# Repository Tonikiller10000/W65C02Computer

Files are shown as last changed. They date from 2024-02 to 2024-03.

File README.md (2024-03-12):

# W65C02Computer

### Description:
This is an 8 bit computer made with the W65C02 processor inspired by Ben Eater.
After board arrival, I will test the clk maximum speed (20MHz), some methods to write into ROM (take\`s too much time to write to it) and some other experiments with this design, beeing made mostly after the Ben Eater\`s original design.

### Features:
 - 8 bit processor
 - 1-10MHz CLK
 - 16K RAM
 - 32K ROM
 - USB C Powered
 - Serial interface
 - Multiple GPIO

<table>
  <tr>
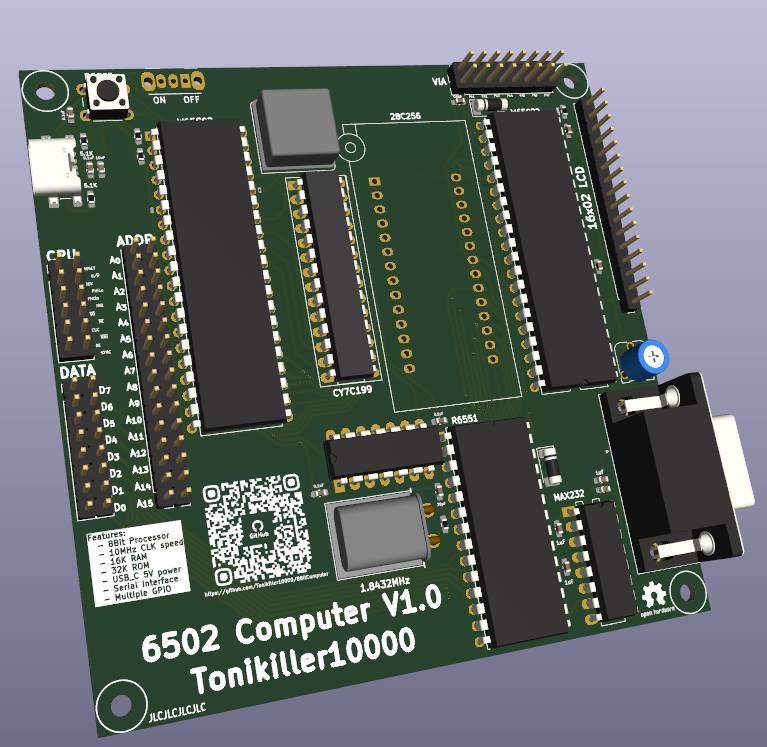
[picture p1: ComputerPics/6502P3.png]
    <td></td>
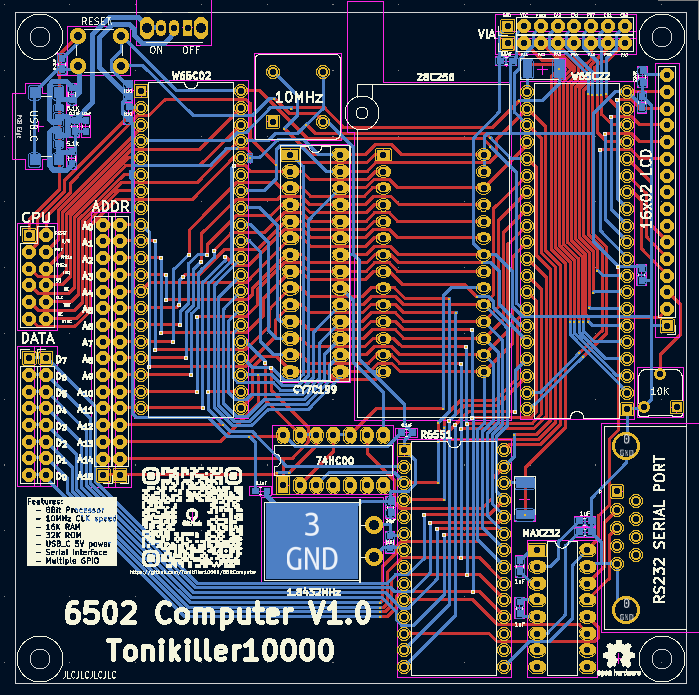
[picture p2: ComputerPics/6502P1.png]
    <td></td>
  </tr>
 </table>

Schematic:  
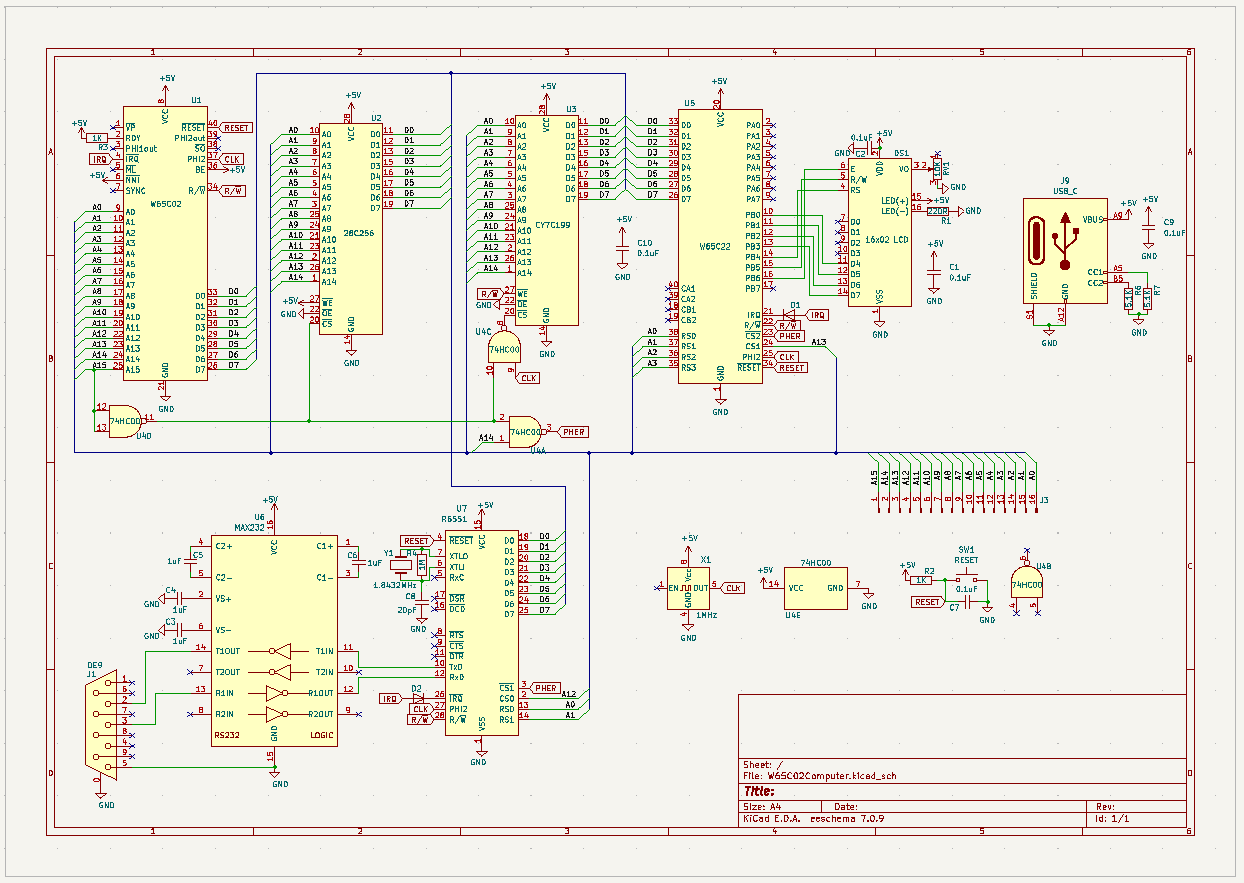
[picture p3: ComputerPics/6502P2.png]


Datasheets:
- W65C02 (Processor): https://eater.net/datasheets/w65c02s.pdf
- W65C22 (VIA): https://eater.net/datasheets/w65c22.pdf
- AT28C256 (32K x 8 EERPOM): https://ww1.microchip.com/downloads/en/DeviceDoc/doc0006.pdf
- CY7c199  (32K x 8  RAM): https://media.digikey.com/pdf/Data%20Sheets/Cypress%20PDFs/CY7C199.pdf
- R6551 (ACIA): https://pdf.datasheetcatalog.com/datasheets/2300/501026_DS.pdf
- MAX232 (Serial Port Driver): https://www.ti.com/lit/ds/symlink/max232.pdf
- MAX232 (Second datasheet): https://pdf1.alldatasheet.com/datasheet-pdf/view/73113/MAXIM/MAX232EPE.html
- 74HC00 (NAND Gate): https://www.diodes.com/assets/Datasheets/74HC00.pdf

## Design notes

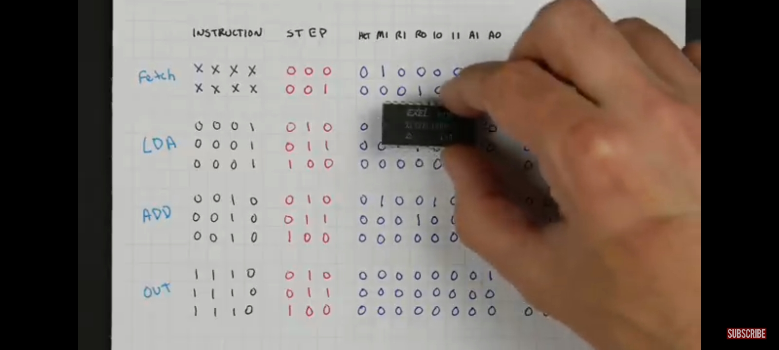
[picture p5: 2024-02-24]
ComputerPics/Screenshot_20221124-123017_YouTube.jpg

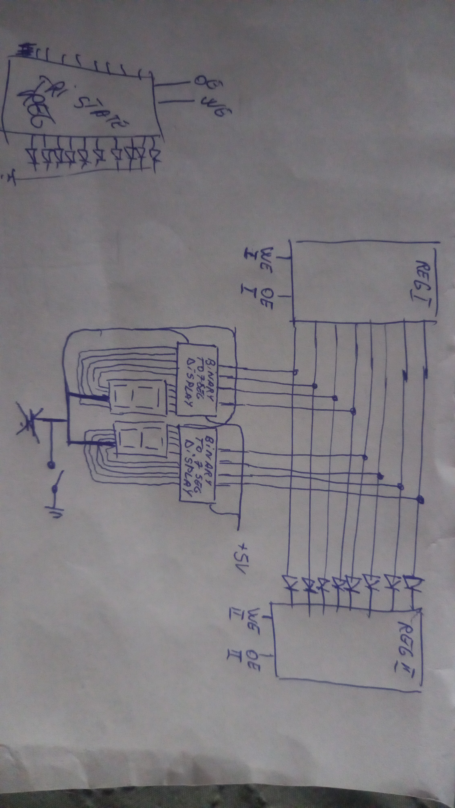
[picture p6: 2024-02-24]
ComputerPics/IMG-20220810-WA0000.jpeg

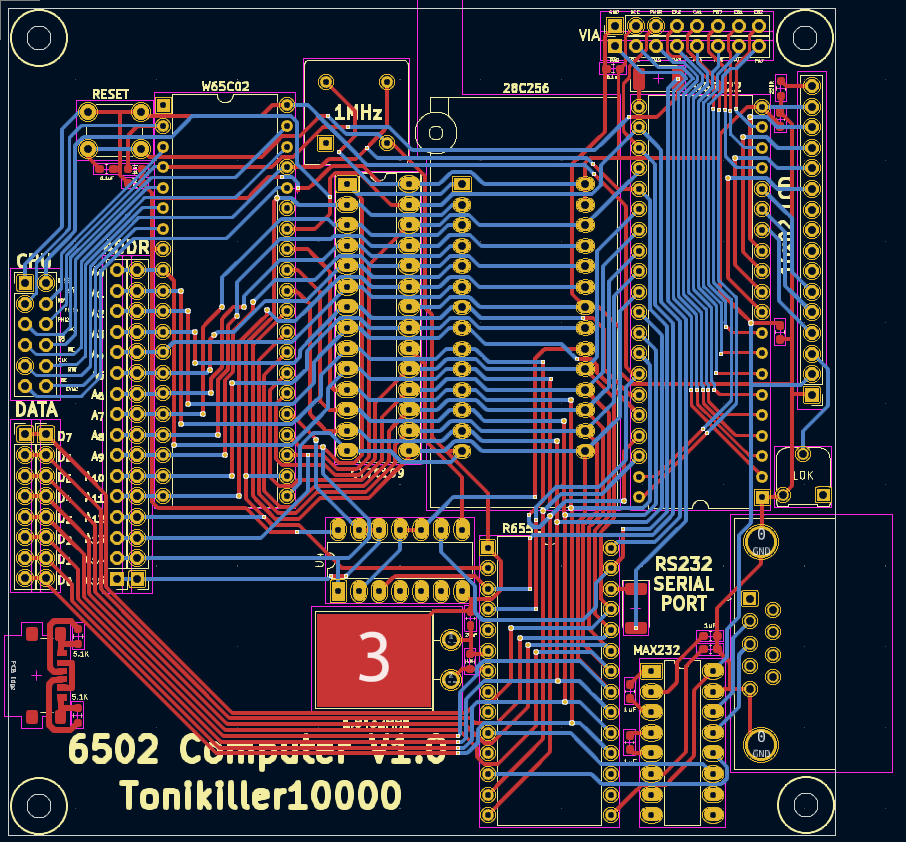
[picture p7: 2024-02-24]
ComputerPics/Screenshot 2024-01-11 041759.png

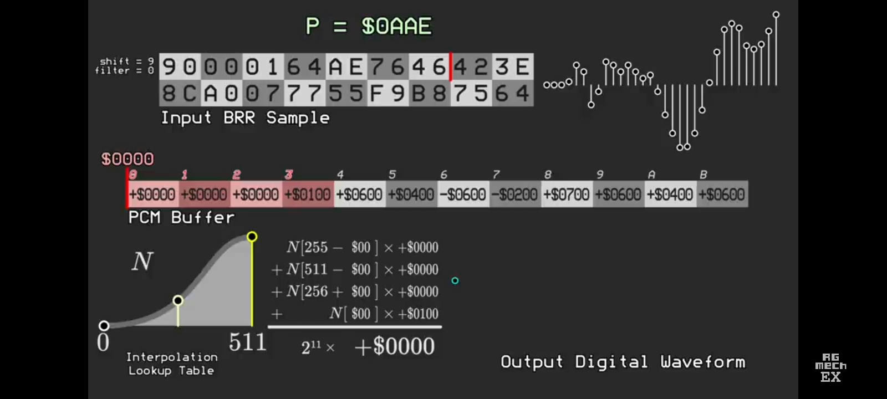
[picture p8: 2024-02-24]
ComputerPics/Screenshot_20220821-015402_YouTube.jpg

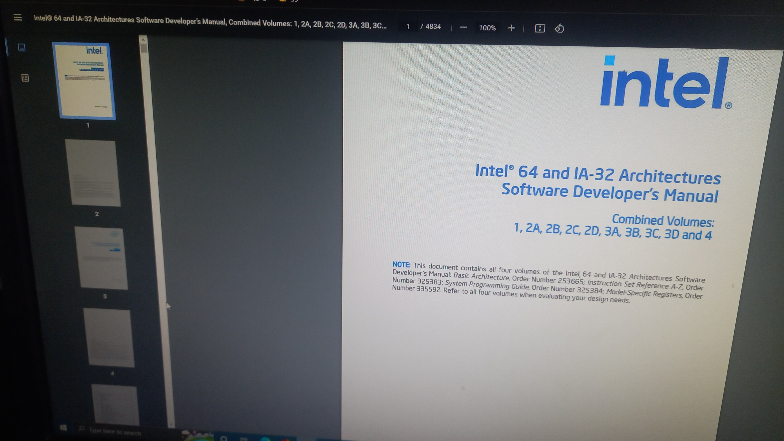
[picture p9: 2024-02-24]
ComputerPics/IMG-20220813-WA0000.jpeg

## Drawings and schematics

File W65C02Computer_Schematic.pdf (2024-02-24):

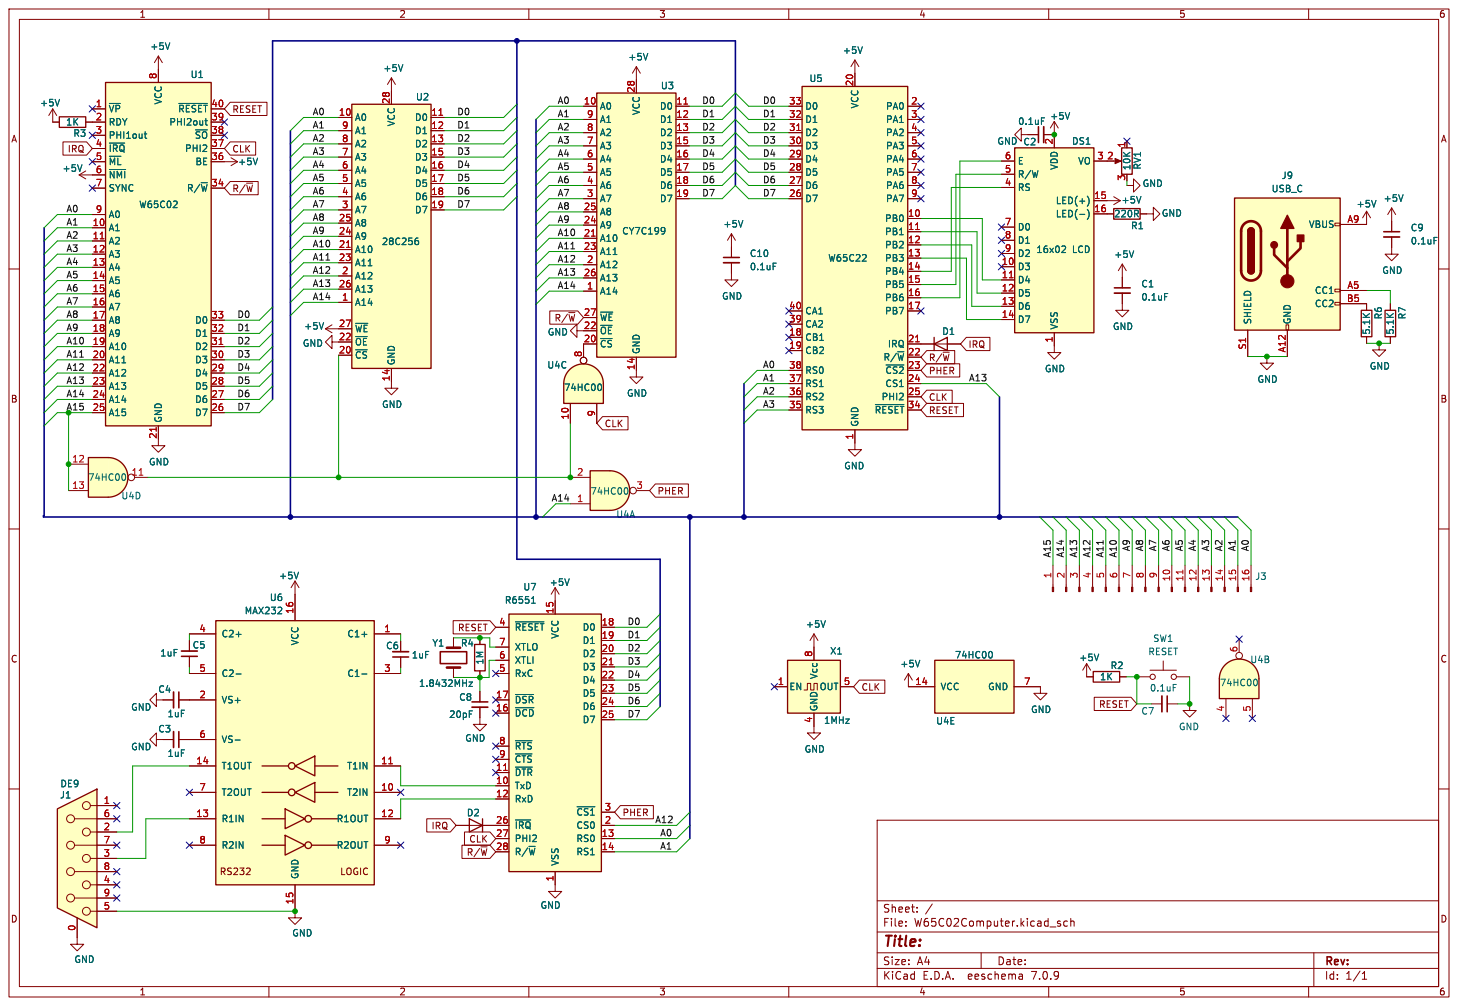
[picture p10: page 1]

1 TxD 10 ~{DTR} 11 RxD 12 RS0 13 RS1 14 VCC 15

4 OUT 5 Vcc 8 GND GND

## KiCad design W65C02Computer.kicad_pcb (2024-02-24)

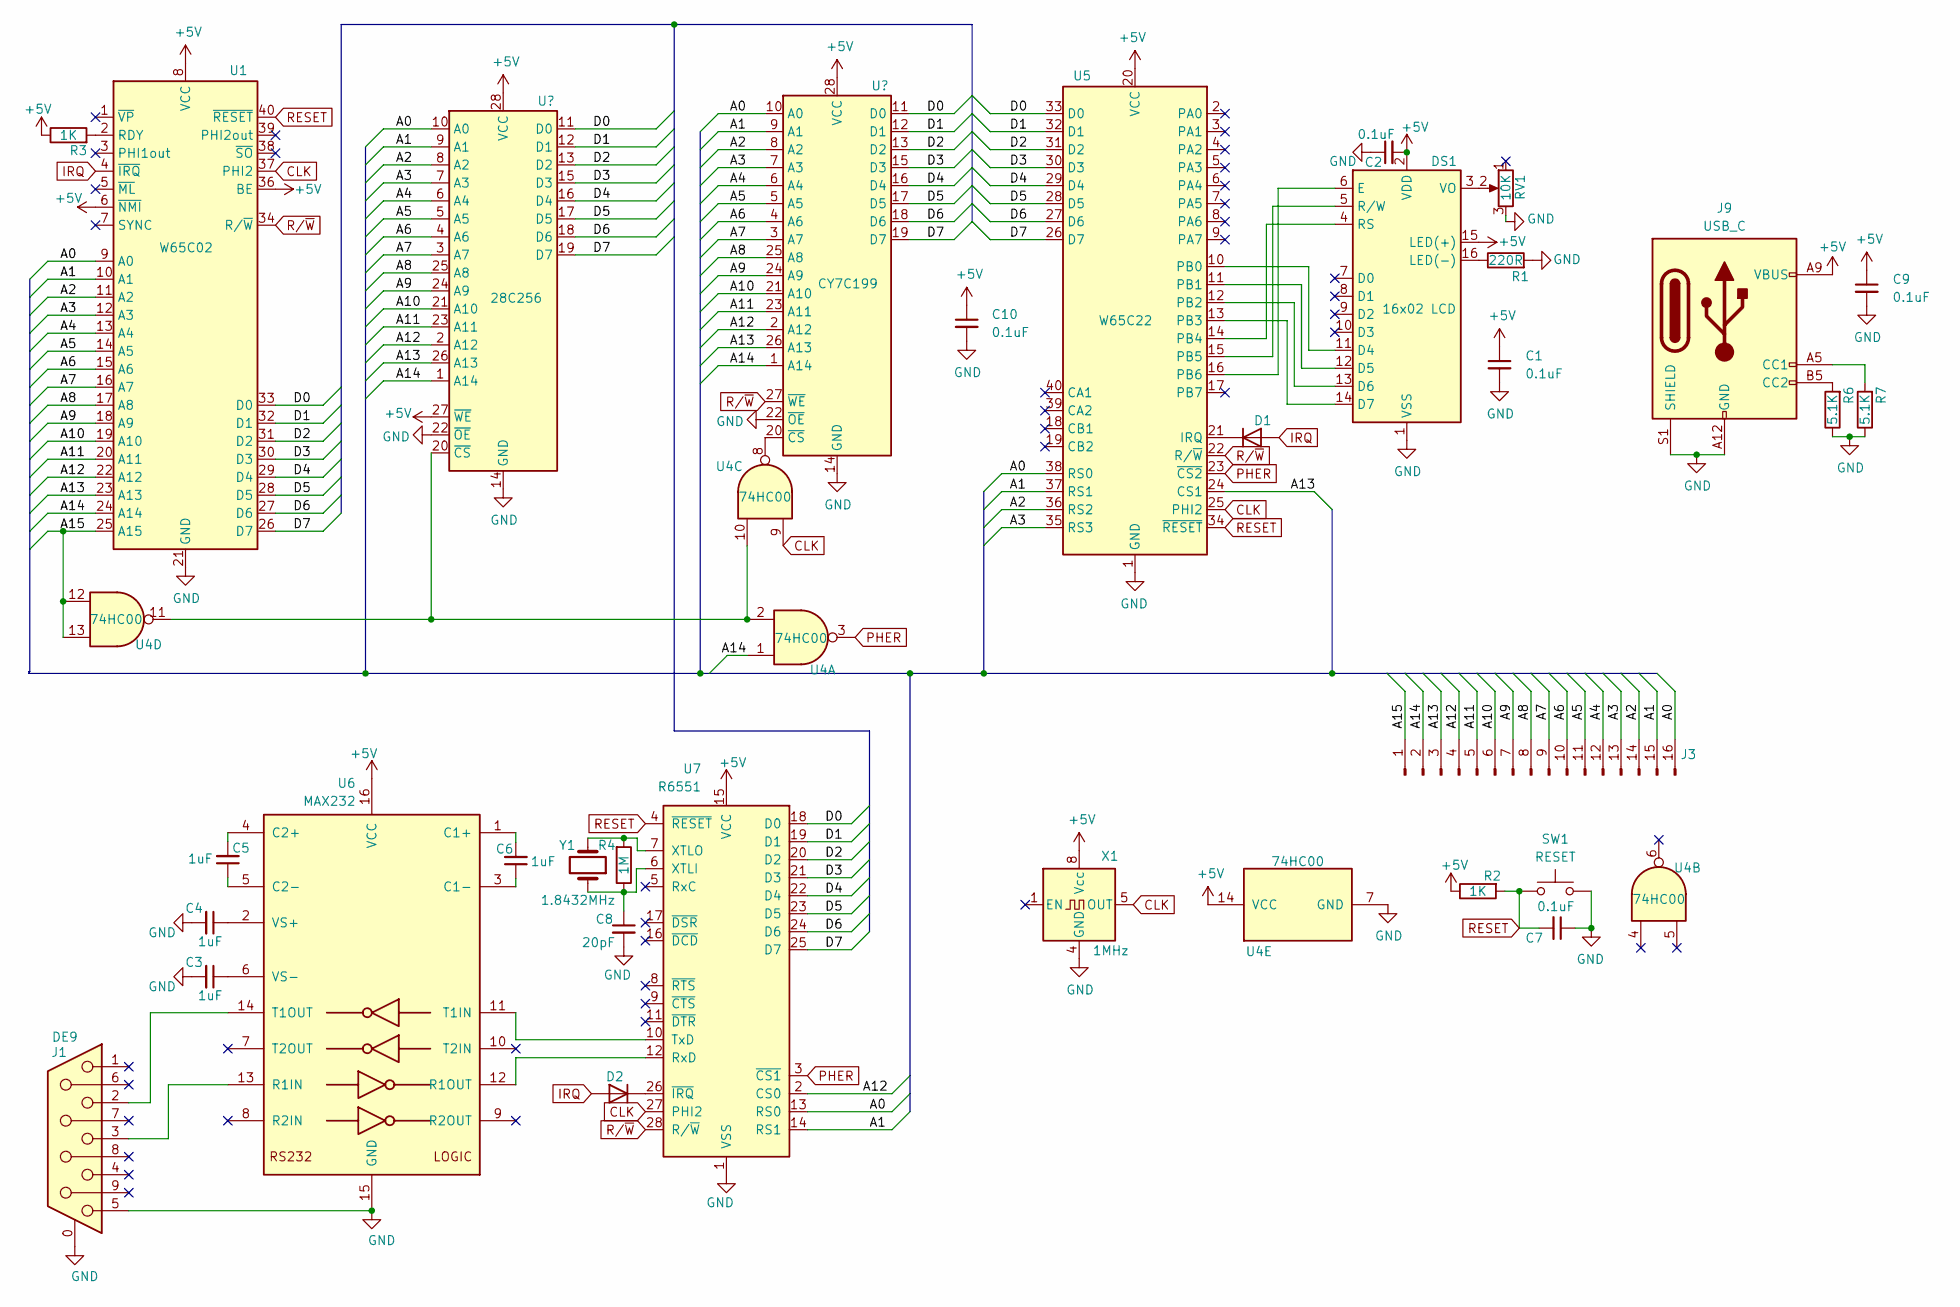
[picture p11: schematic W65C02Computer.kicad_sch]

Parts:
C1, C2, C7, C9, C10: 0.1uF; C_0603_1608Metric_Pad1.08x0.95mm_HandSolder
C3, C4, C5, C6: 1uF; C_0603_1608Metric_Pad1.08x0.95mm_HandSolder
C8: 20pF; C_0603_1608Metric_Pad1.08x0.95mm_HandSolder
D1, D2: D; D_MELF
DS1: 16x02 LCD; PinHeader_1x16_P2.54mm_Vertical
J1: DE9; DSUB-9_Female_Horizontal_P2.77x2.84mm_EdgePinOffset7.70mm_H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
J3: Conn_01x16_Pin; PinHeader_1x16_P2.54mm_Vertical
J9: USB_C
R1: 220R; R_0603_1608Metric_Pad0.98x0.95mm_HandSolder
R2, R3: 1K; R_0603_1608Metric_Pad0.98x0.95mm_HandSolder
R4: 1M; R_0603_1608Metric_Pad0.98x0.95mm_HandSolder
R6, R7: 5.1K; R_0603_1608Metric_Pad0.98x0.95mm_HandSolder
RV1: 10K; Potentiometer_Runtron_RM-065_Vertical
SW1: RESET; SW_PUSH_6mm
U1: W65C02; DIP-40_W15.24mm
U2: 28C256; DIP-28_W15.24mm_Socket
U3: CY7C199; DIP-28_W7.62mm_LongPads
U4: 74HC00; DIP-14_W7.62mm_LongPads
U5: W65C22; DIP-40_W15.24mm
U6: MAX232; DIP-16_W7.62mm_LongPads
U7: R6551; DIP-28_W15.24mm
X1: 1MHz; Oscillator_DIP-8
Y1: 1.8432MHz; Crystal_HC50_Horizontal_1EP_style1

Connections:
+5V: C1.1, C2.2, C9.1, C10.1, DS1.2 (VDD), DS1.15 (LED(+)), J9.A9 (VBUS), J9.B9 (VBUS), R2.1, R3.1, U1.6 (~NMI), U1.8 (VCC), U1.36 (BE), U2.27 (~WE), U2.28 (VCC), U3.28 (VCC), U4.14 (VCC), U5.20 (VCC), U6.16 (VCC), U7.15 (VCC), X1.8 (Vcc); also elsewhere on the board
/A0: J3.16, U1.9 (A0), U2.10 (A0), U3.10 (A0), U5.38 (RS0), U7.13 (RS0)
/A1: J3.15, U1.10 (A1), U2.9 (A1), U3.9 (A1), U5.37 (RS1), U7.14 (RS1)
/A2: J3.14, U1.11 (A2), U2.8 (A2), U3.8 (A2), U5.36 (RS2)
/A3: J3.13, U1.12 (A3), U2.7 (A3), U3.7 (A3), U5.35 (RS3)
/A4: J3.12, U1.13 (A4), U2.6 (A4), U3.6 (A4)
/A5: J3.11, U1.14 (A5), U2.5 (A5), U3.5 (A5)
/A6: J3.10, U1.15 (A6), U2.4 (A6), U3.4 (A6)
/A7: J3.9, U1.16 (A7), U2.3 (A7), U3.3 (A7)
/A8: J3.8, U1.17 (A8), U2.25 (A8), U3.25 (A8)
/A9: J3.7, U1.18 (A9), U2.24 (A9), U3.24 (A9)
/A10: J3.6, U1.19 (A10), U2.21 (A10), U3.21 (A10)
/A11: J3.5, U1.20 (A11), U2.23 (A11), U3.23 (A11)
/A12: J3.4, U1.22 (A12), U2.2 (A12), U3.2 (A12), U7.2 (CS0)
/A13: J3.3, U1.23 (A13), U2.26 (A13), U3.26 (A13), U5.24 (CS1)
/A14: J3.2, U1.24 (A14), U2.1 (A14), U3.1 (A14), U4.1
/A15: J3.1, U1.25 (A15), U4.12, U4.13
/D0: U1.33 (D0), U2.11 (D0), U3.11 (D0), U5.33 (D0), U7.18 (D0)
/D1: U1.32 (D1), U2.12 (D1), U3.12 (D1), U5.32 (D1), U7.19 (D1)
/D2: U1.31 (D2), U2.13 (D2), U3.13 (D2), U5.31 (D2), U7.20 (D2)
/D3: U1.30 (D3), U2.15 (D3), U3.15 (D3), U5.30 (D3), U7.21 (D3)
/D4: U1.29 (D4), U2.16 (D4), U3.16 (D4), U5.29 (D4), U7.22 (D4)
/D5: U1.28 (D5), U2.17 (D5), U3.17 (D5), U5.28 (D5), U7.23 (D5)
/D6: U1.27 (D6), U2.18 (D6), U3.18 (D6), U5.27 (D6), U7.24 (D6)
/D7: U1.26 (D7), U2.19 (D7), U3.19 (D7), U5.26 (D7), U7.25 (D7)
CLK: U1.37 (PHI2), U4.9, U5.25 (PHI2), U7.27 (PHI2), X1.5 (OUT)
GND: C1.2, C2.1, C3.2, C4.2, C7.1, C8.2, C9.2, C10.2, DS1.1 (VSS), J1.0 (PAD), J1.5, J9.A12 (GND), J9.B12 (GND), J9.S1 (SHIELD), R1.2, R6.1, R7.1, RV1.3, SW1.1, U1.21 (GND), U2.14 (GND), U2.22 (~OE), U3.14 (GND), U3.22 (~OE), U4.7 (GND), U5.1 (GND), U6.15 (GND), U7.1 (VSS), X1.4 (GND), Y1.3; also elsewhere on the board
IRQ: D1.2 (A), D2.2 (A), U1.4 (~IRQ)
unnamed: D1.1 (K), U5.21 (IRQ)
unnamed: D2.1 (K), U7.26 (~IRQ)
unnamed: DS1.11 (D4), U5.10 (PB0)
unnamed: DS1.12 (D5), U5.11 (PB1)
unnamed: DS1.13 (D6), U5.12 (PB2)
unnamed: DS1.14 (D7), U5.13 (PB3)
unnamed: DS1.6 (E), U5.16 (PB6)
unnamed: DS1.16 (LED(-)), R1.1
unnamed: DS1.4 (RS), U5.14 (PB4)
unnamed: DS1.5 (R/W), U5.15 (PB5)
unnamed: DS1.3 (VO), RV1.2
unnamed: J9.A5 (CC1), R7.2
unnamed: J9.B5 (CC2), R6.2
unnamed: R3.2, U1.2 (RDY)
unnamed: U2.20 (~CS), U4.2, U4.10, U4.11
unnamed: U3.20 (~CS), U4.8
unnamed: C6.2, U6.1 (C1+)
unnamed: C6.1, U6.3 (C1-)
unnamed: C5.2, U6.4 (C2+)
unnamed: C5.1, U6.5 (C2-)
unnamed: J1.3, U6.13 (R1IN)
unnamed: U6.12 (R1OUT), U7.12 (RxD)
unnamed: U6.11 (T1IN), U7.10 (TxD)
unnamed: J1.2, U6.14 (T1OUT)
unnamed: C4.1, U6.2 (VS+)
unnamed: C3.1, U6.6 (VS-)
unnamed: C8.1, R4.1, U7.6 (XTLI), Y1.1
unnamed: R4.2, U7.7 (XTLO), Y1.2
PHER: U4.3, U5.23 (~CS2), U7.3 (~CS1)
RESET: C7.2, R2.2, SW1.2, U1.40 (~RESET), U5.34 (~RESET), U7.4 (~RESET)
R/~W: U1.34 (R/~W), U3.27 (~WE), U5.22 (R/~W), U7.28 (R/~W)

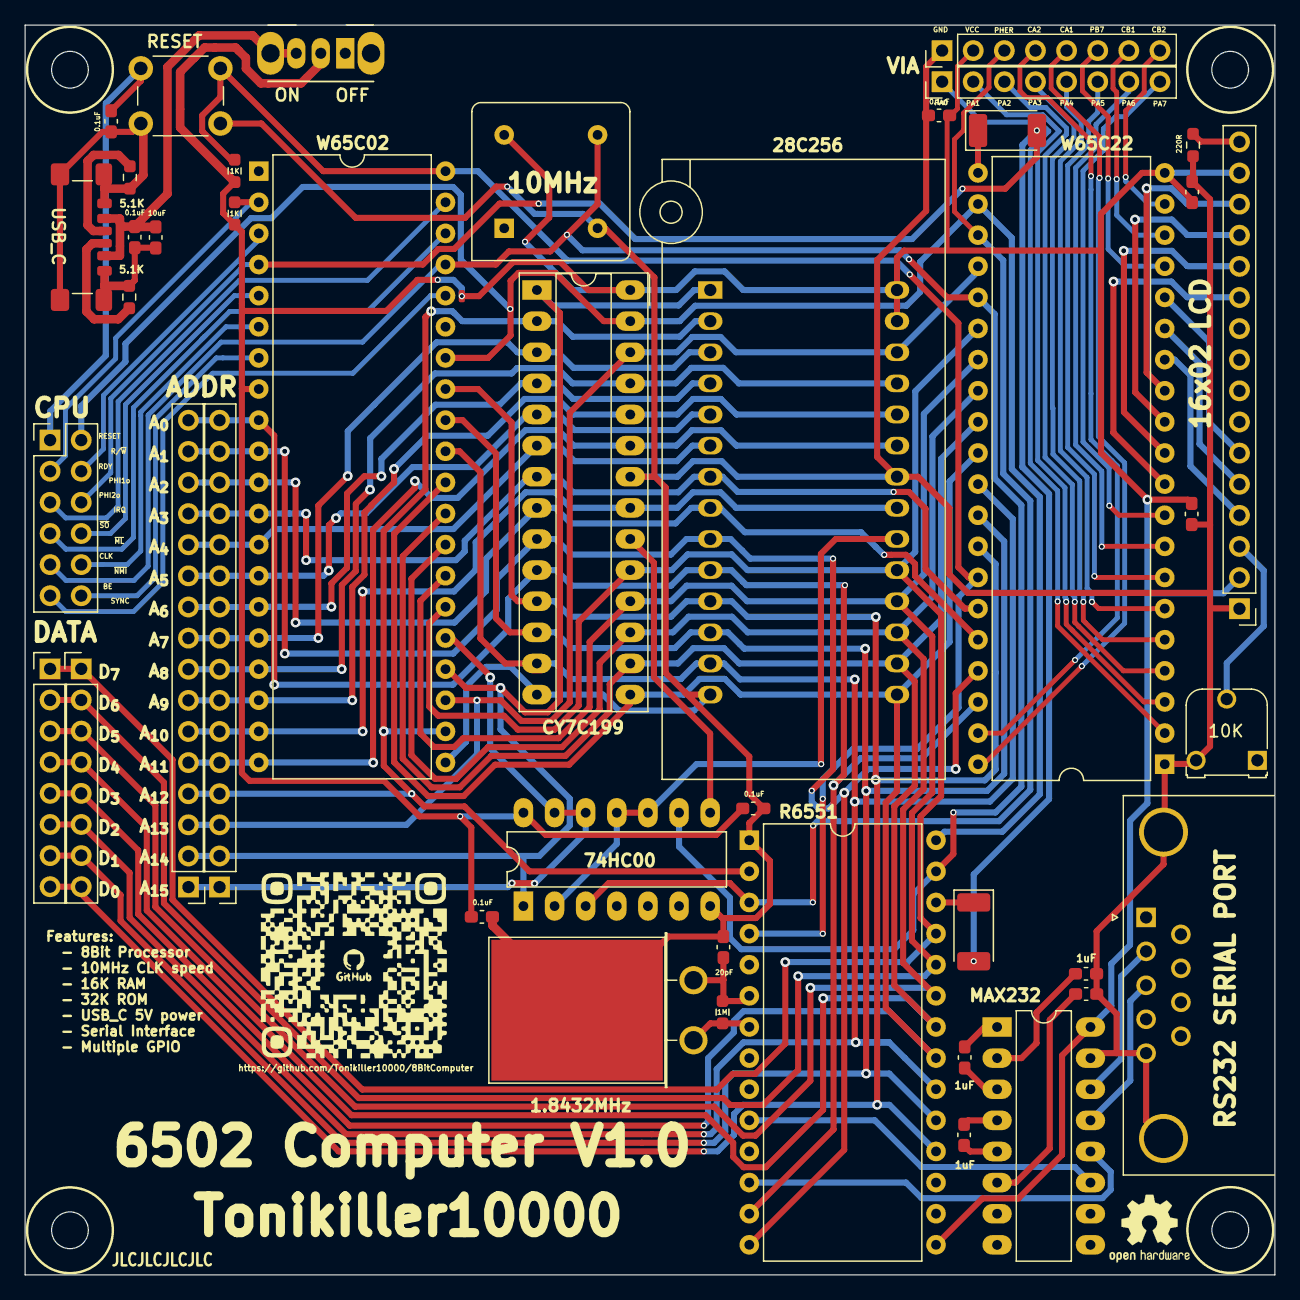
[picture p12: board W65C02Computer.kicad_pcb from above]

Board: 2 copper layers, 102.0 x 102.0 mm, 37 parts (0 on the bottom side), 59 nets.

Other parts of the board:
C9#2, C9#3: 0.1uF; C_0603_1608Metric_Pad1.08x0.95mm_HandSolder
C9#4: 10uF; C_0603_1608Metric_Pad1.08x0.95mm_HandSolder
SW2: SW_SPDT; SW_CuK_OS102011MA1QN1_SPDT_Angled

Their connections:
+5V: C9#3.1; also elsewhere on the board
GND: C9#3.2; also elsewhere on the board
